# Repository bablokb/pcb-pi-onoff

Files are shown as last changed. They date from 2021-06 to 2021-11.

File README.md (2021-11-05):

pcb-pi-onoff
============

Overview
--------

This project contains the KiCAD-project-files for a small
power-control pHat. A PIC-MCU controls the power for the Pi. On/off is
via a push-button or an IR-remote. Before cutting current, the PIC
sends a shutdown request to the Pi. Once done, the Pi signals
shutdown-complete to the PIC which in turn cuts power.

Status
------

**this is work-in-progress!**

  - production: OK
  - basic firmware: tested
  - basic functional test: open
  - test with RTC: open
  - IR firmware: open
  - IR test: open

PCB
---

The KiCAD-sources for the pHat are in the sub-directory
[pcb-pi-onoff](pcb-pi-onoff), production-files with
gerber-layers, drill-hole files, bom and pick-and-place-file are in
the sub-directory [production](production). Note that the pcb and the
bom/cpl-files are optimzied for JLCPCB. Please check with your
pcb-factory if these files meet their requirements.

Schematic
---------

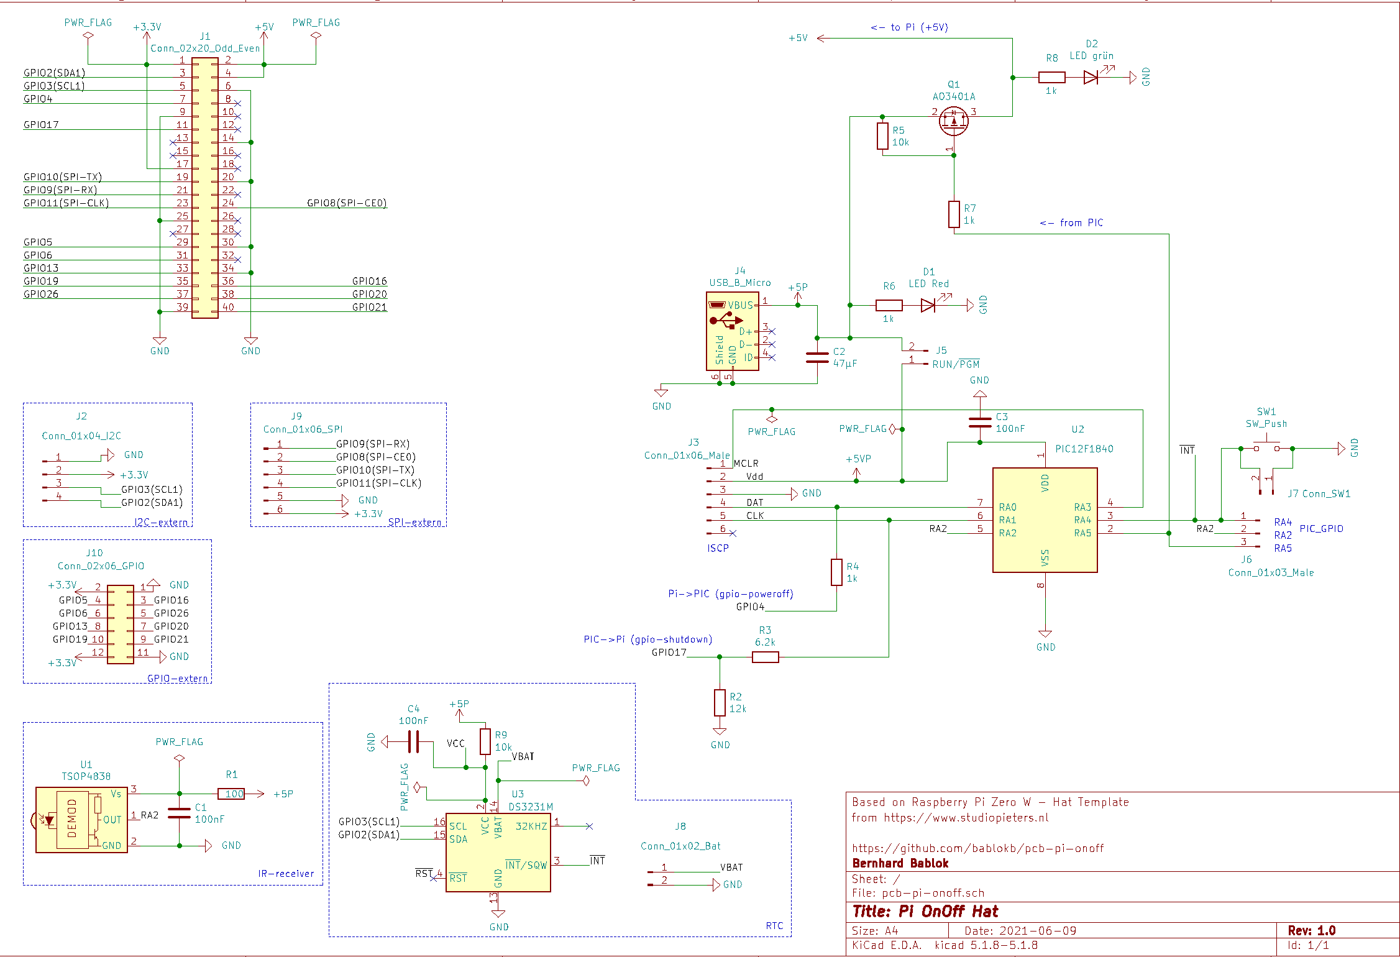
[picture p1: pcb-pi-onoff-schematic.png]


Layout
------

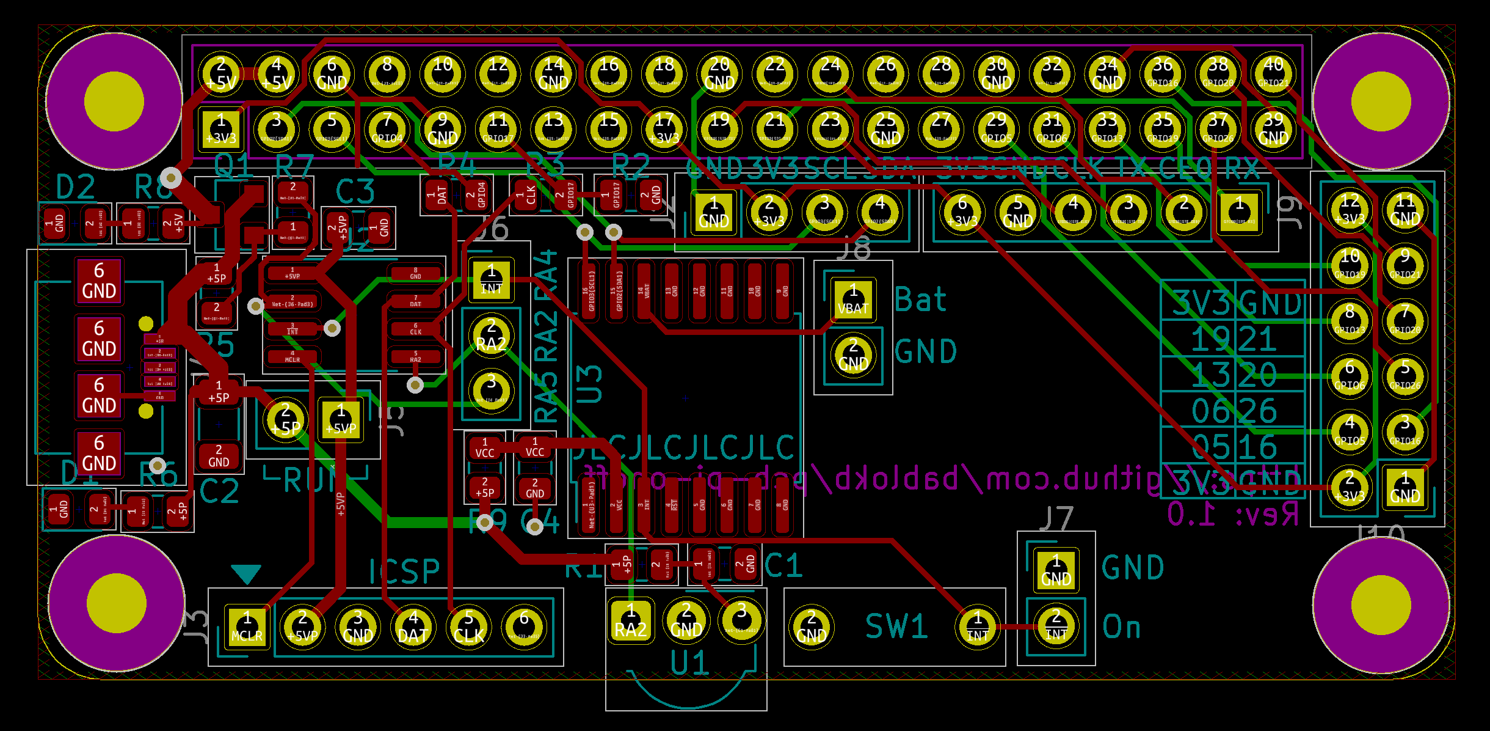
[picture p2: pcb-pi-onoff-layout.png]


3D-View
-------

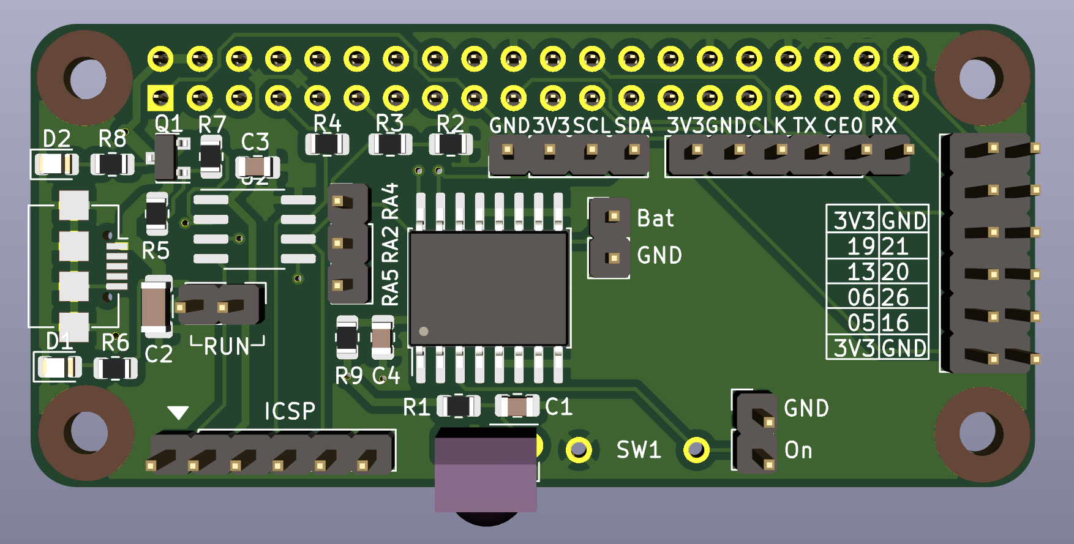
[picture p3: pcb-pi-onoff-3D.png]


Configuration
-------------

Please read the description of the [firmware](pic-firmware/README.md) for
how to configure the Pi and the PIC.

License
-------

[![CC BY-SA 4.0][cc-by-sa-shield]][cc-by-sa]

This work is licensed under a
[Creative Commons Attribution-ShareAlike 4.0 International
License][cc-by-sa].

[][cc-by-sa]

[cc-by-sa]: http://creativecommons.org/licenses/by-sa/4.0/
[cc-by-sa-image]: https://licensebuttons.net/l/by-sa/4.0/88x31.png
[cc-by-sa-shield]:
https://img.shields.io/badge/License-CC%20BY--SA%204.0-lightgrey.svg

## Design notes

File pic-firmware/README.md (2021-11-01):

Firmware
========

About
-----

This is a simple "firmware" for the power-control pHat.

  - The power of the Raspberry Pi is controlled by a PIC using a mosfet.
  - On a signal (high->low), the PIC sets the gate of the mosfet
    to low, thus turning on the Pi. Afterward the PIC waits for
    five seconds. This gives the Pi time to setup it's GPIOs correctly.
  - On an external signal (high->low), the PIC requests the Pi to shutdown by
    setting an output pin to low. This output pin is connected to and
    monitored by the Pi (see below).
  - The Pi now shuts down and at the end sets another pin to high
    This pin in turn is connected to and monitored by the PIC. The PIC
    sets the gate to high thus turning power off.

For the details of the connections, see the
[schematic](../pcb-pi-onoff-schematic.png).

The external signal is connected to a push-button and (optional) to
a RTC.

PIC Configuration
-----------------

  - RA/GP0: PIN_FROM_PI (low->high, connected to GPIO04 on the Pi-side (physical
    pin 7). This is the same pin as in the gpio-poweroff overlay.
  - RA/GP1: PIN_TO_PI (high->low, shutdown-request, monitored by the Pi).
    Connected to GPIO17 on the Pi-side. This is the same pin as in the 
    gpio-shutdown overlay.
  - RA/GP2: PIN_IR (not implemented yet)
  - RA/GP3: only connected to the ICSP-interface
  - RA/GP4: PIN_SIG (high->low, button, RTC)
  - RA/GP5: PIN_POWER (connected to the gate of the mosfet)

In this scenario, the PIC should run at 5V to provide enough voltage to
the gate of the mosfet. So PIN_TO_PI needs a voltage divider when
connected to the Pi (part of the pcb).

Pi Configuration
----------------

On the Pi-side you have to add the following lines in your
/boot/config.xt:

    # initiate shutdown on high->low
    dtoverlay=gpio-shutdown,gpio_pin=17,gpio_pull=off
    # signal shutdown complete on low->high
    dtoverlay=gpio-poweroff,gpiopin=4

Be careful, one overlay needs *gpio_pin*, the other *gpiopin*!

Building
--------

You need sdcc, gpasm and pk2cmd to build and flash the firmware. Please
adapt the paths within the file `rules.inc` to suit your setup.

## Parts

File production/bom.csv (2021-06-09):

Comment | Designator | Footprint | LCSC
47µF | C2 | Capacitor_SMD:C_1206_3216Metric | C96123
100nF | C1,C3,C4 | Capacitor_SMD:C_0805_2012Metric | C24497
LED Red | D1 | LED_SMD:LED_0805_2012Metric | C84256
LED grün | D2 | LED_SMD:LED_0805_2012Metric | C2297
Conn_02x20_Odd_Even | J1 | Connector_PinSocket_2.54mm:PinSocket_2x20_P2.54mm_Vertical
Conn_02x06_GPIO | J10 | Connector_PinHeader_2.54mm:PinHeader_2x06_P2.54mm_Vertical
Conn_01x04_I2C | J2 | Connector_PinHeader_2.54mm:PinHeader_1x04_P2.54mm_Vertical
Conn_01x06_Male | J3 | Connector_PinHeader_2.54mm:PinHeader_1x06_P2.54mm_Vertical
USB_B_Micro | J4 | user:USB_Micro-B_JLCPCB_40942 | C40942
RUN/~PGM~ | J5 | Connector_PinHeader_2.54mm:PinHeader_1x02_P2.54mm_Vertical
Conn_01x03_Male | J6 | Connector_PinHeader_2.54mm:PinHeader_1x03_P2.54mm_Vertical
Conn_SW1 | J7 | Connector_PinHeader_2.54mm:PinHeader_1x02_P2.54mm_Vertical
Conn_01x02_Bat | J8 | Connector_PinHeader_2.54mm:PinHeader_1x02_P2.54mm_Vertical
Conn_01x06_SPI | J9 | Connector_PinHeader_2.54mm:PinHeader_1x06_P2.54mm_Vertical
AO3401A | Q1 | Package_TO_SOT_SMD:SOT-23 | C15127
100 | R1 | Resistor_SMD:R_0805_2012Metric | C17408
12k | R2 | Resistor_SMD:R_0805_2012Metric | C17444
6.2k | R3 | Resistor_SMD:R_0805_2012Metric | C17767
10k | R5,R9 | Resistor_SMD:R_0805_2012Metric | C17414
1k | R4,R6,R7,R8 | Resistor_SMD:R_0805_2012Metric | C17513
SW_Push | SW1 | user:SW_PUSH_SLIM_1x4
TSOP4838 | U1 | OptoDevice:Vishay_MOLD-3Pin
PIC12F1840 | U2 | Package_SO:SO-8_3.9x4.9mm_P1.27mm
DS3231M | U3 | Package_SO:SOIC-16W_7.5x10.3mm_P1.27mm

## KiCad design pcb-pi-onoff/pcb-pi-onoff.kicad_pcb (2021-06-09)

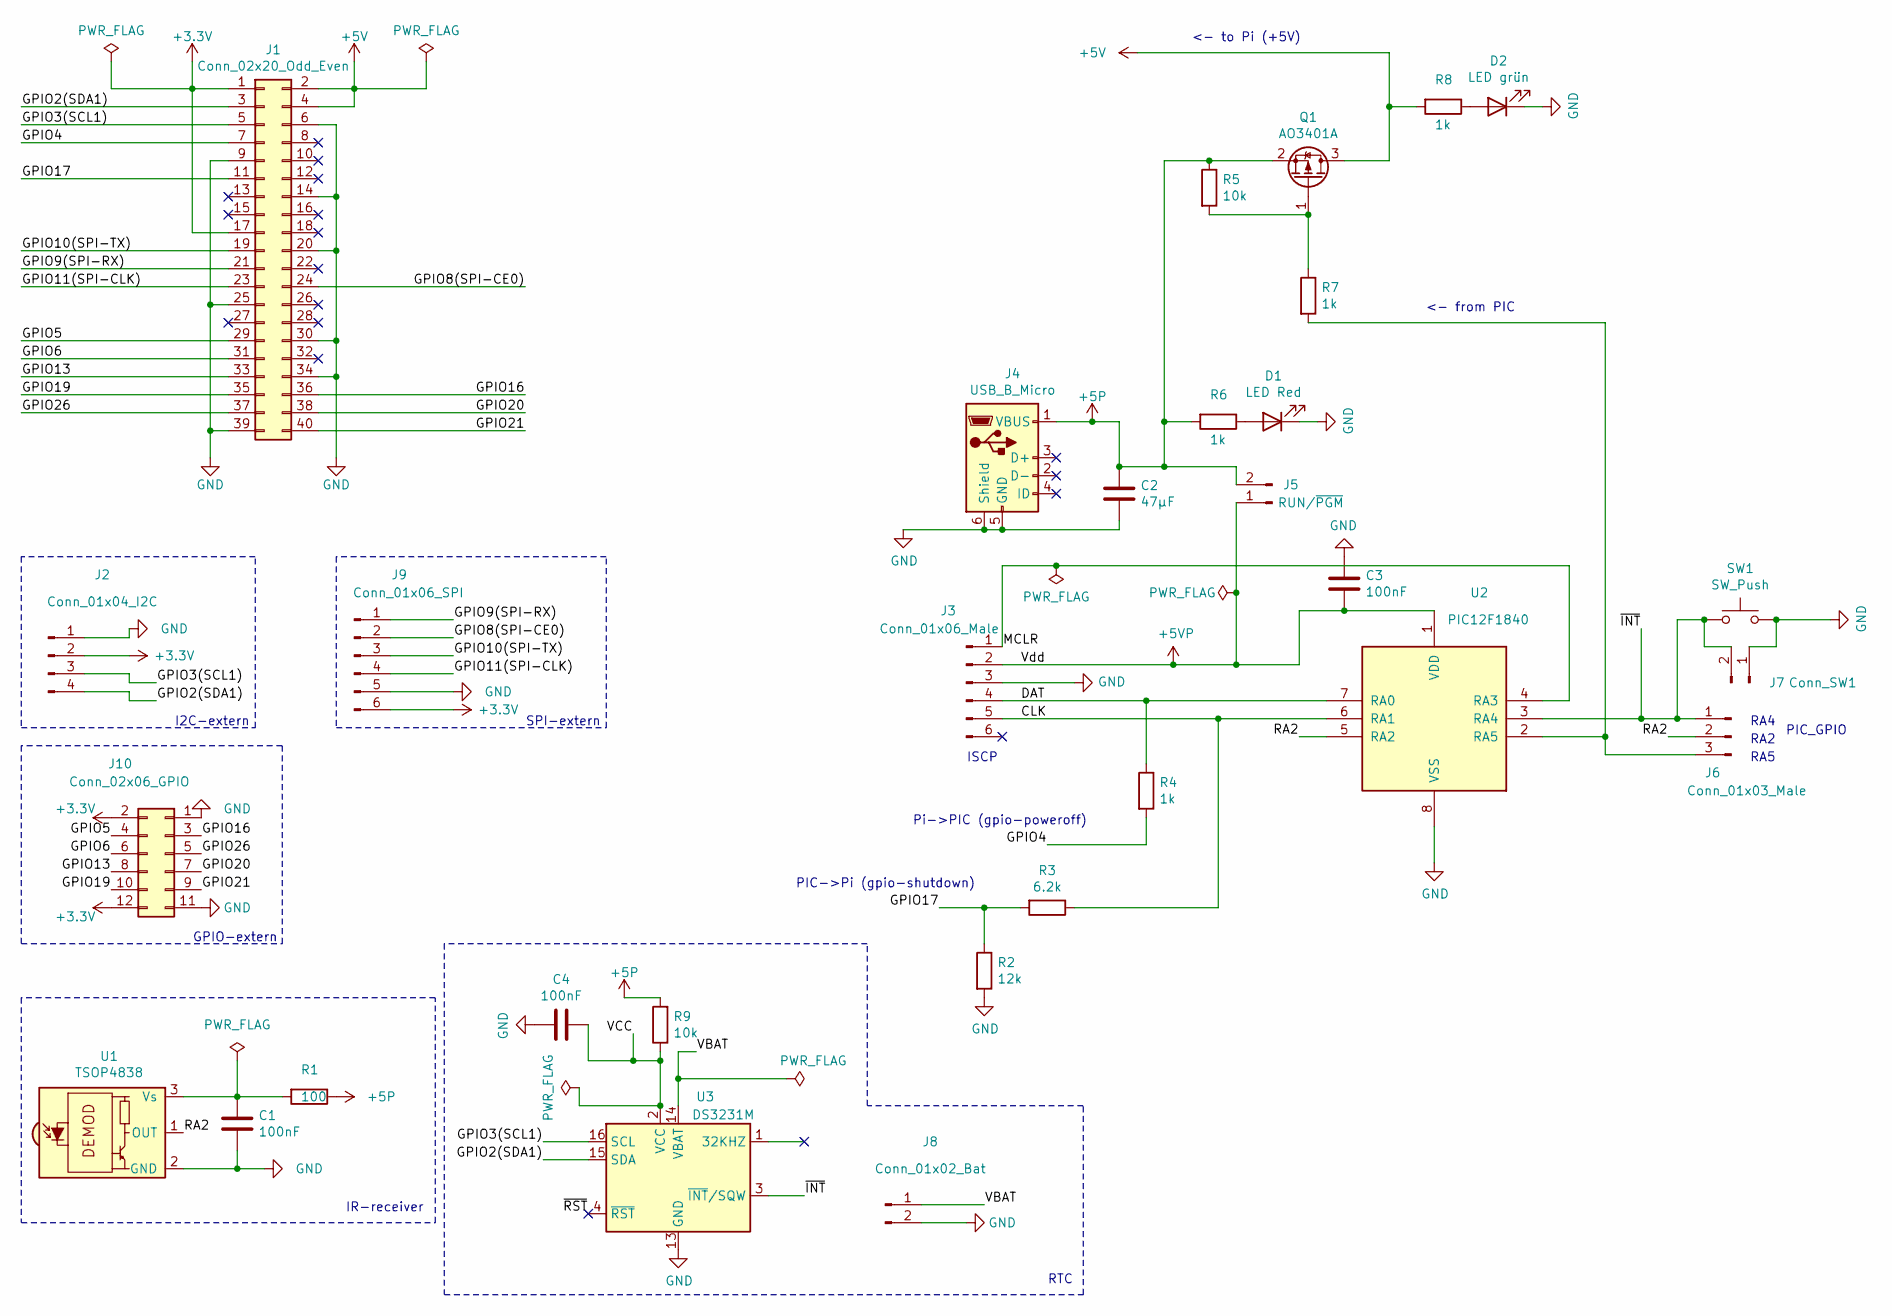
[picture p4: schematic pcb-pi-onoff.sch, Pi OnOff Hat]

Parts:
C1, C3, C4: 100nF; C_0805_2012Metric; LCSC C24497
C2: 47µF; C_1206_3216Metric; LCSC C96123
D1: LED Red; LED_0805_2012Metric; LCSC C84256
D2: LED grün; LED_0805_2012Metric; LCSC C2297
J1: Conn_02x20_Odd_Even; PinSocket_2x20_P2.54mm_Vertical
J2: Conn_01x04_I2C; PinHeader_1x04_P2.54mm_Vertical
J3: Conn_01x06_Male; PinHeader_1x06_P2.54mm_Vertical
J4: USB_B_Micro; USB_Micro-B_JLCPCB_40942; LCSC C40942
J5: RUN/~PGM~; PinHeader_1x02_P2.54mm_Vertical
J6: Conn_01x03_Male; PinHeader_1x03_P2.54mm_Vertical
J7: Conn_SW1; PinHeader_1x02_P2.54mm_Vertical
J8: Conn_01x02_Bat; PinHeader_1x02_P2.54mm_Vertical
J9: Conn_01x06_SPI; PinHeader_1x06_P2.54mm_Vertical
J10: Conn_02x06_GPIO; PinHeader_2x06_P2.54mm_Vertical
Q1: AO3401A; SOT-23; LCSC C15127
R1: 100; R_0805_2012Metric; LCSC C17408
R2: 12k; R_0805_2012Metric; LCSC C17444
R3: 6.2k; R_0805_2012Metric; LCSC C17767
R4, R6, R7, R8: 1k; R_0805_2012Metric; LCSC C17513
R5, R9: 10k; R_0805_2012Metric; LCSC C17414
SW1: SW_Push; SW_PUSH_SLIM_1x4
U1: TSOP4838; Vishay_MOLD-3Pin
U2: PIC12F1840; SO-8_3.9x4.9mm_P1.27mm_HandSolder
U3: DS3231M; SOIC-16W_7.5x10.3mm_P1.27mm_HandSolder

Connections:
+3V3: J1.1, J1.17, J2.2, J9.6, J10.2, J10.12
+5P: C2.1, J4.1 (VBUS), J5.2, Q1.2 (S), R1.1, R5.1, R6.2, R9.2
+5V: J1.2, J1.4, Q1.3 (D), R8.2
+5VP: C3.2, J3.2, J5.1, U2.1 (VDD)
/CLK: J3.5, R3.1, U2.6 (RA1)
/DAT: J3.4, R4.1, U2.7 (RA0)
/GPIO2(SDA1): J1.3, J2.4, U3.15 (SDA)
/GPIO3(SCL1): J1.5, J2.3, U3.16 (SCL)
/GPIO4: J1.7, R4.2
/GPIO5: J1.29, J10.4
/GPIO6: J1.31, J10.6
/GPIO8(SPI-CE0): J1.24, J9.2
/GPIO9(SPI-RX): J1.21, J9.1
/GPIO10(SPI-TX): J1.19, J9.3
/GPIO11(SPI-CLK): J1.23, J9.4
/GPIO13: J1.33, J10.8
/GPIO16: J1.36, J10.3
/GPIO17: J1.11, R2.1, R3.2
/GPIO19: J1.35, J10.10
/GPIO20: J1.38, J10.7
/GPIO21: J1.40, J10.9
/GPIO26: J1.37, J10.5
/MCLR: J3.1, U2.4 (RA3)
/RA2: J6.2, U1.1 (OUT), U2.5 (RA2)
/VBAT: J8.1, U3.14 (VBAT)
/VCC: C4.1, R9.1, U3.2 (VCC)
/~INT: J6.1, J7.2, SW1.1, U2.3 (RA4), U3.3 (~INT~/SQW)
/~RST: U3.4 (~RST)
GND: C1.2, C2.2, C3.1, C4.2, D1.1 (K), D2.1 (K), J1.6, J1.9, J1.14, J1.20, J1.25, J1.30, J1.34, J1.39, J2.1, J3.3, J4.5 (GND), J4.6 (Shield), J7.1, J8.2, J9.5, J10.1, J10.11, R2.2, SW1.2, U1.2 (GND), U2.8 (VSS), U3.5 (GND), U3.6 (GND), U3.7 (GND), U3.8 (GND), U3.9 (GND), U3.10 (GND), U3.11 (GND), U3.12 (GND), U3.13 (GND)
unnamed: C1.1, R1.2, U1.3 (Vs)
unnamed: D1.2 (A), R6.1
unnamed: D2.2 (A), R8.1
unnamed: J6.3, R7.2, U2.2 (RA5)
unnamed: Q1.1 (G), R5.2, R7.1

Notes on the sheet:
PIC_GPIO
ISCP
Pi->PIC (gpio-poweroff)
PIC->Pi (gpio-shutdown)
RA4
RA2
<- from PIC
<- to Pi (+5V)
RA5
I2C-extern
SPI-extern
GPIO-extern
IR-receiver
RTC

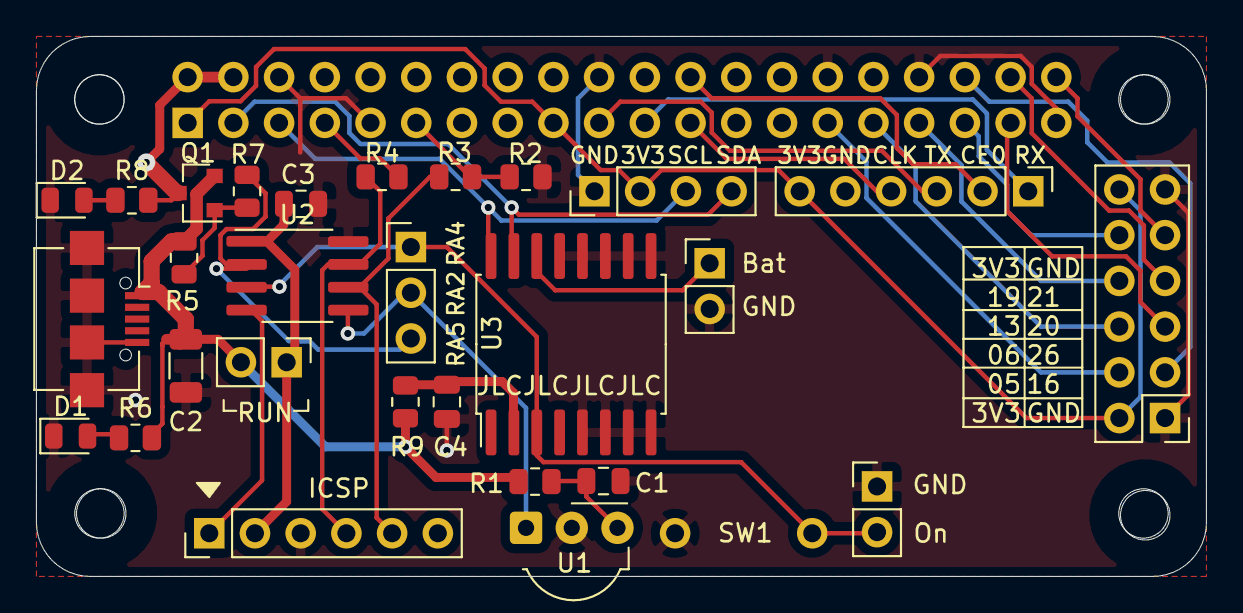
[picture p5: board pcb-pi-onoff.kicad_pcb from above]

Board: 2 copper layers, 65.0 x 30.0 mm, 30 parts (1 on the bottom side), 33 nets.

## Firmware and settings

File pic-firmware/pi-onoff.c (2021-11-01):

// --------------------------------------------------------------------------
// Firmware for power-control pHat
//
// This project uses the following pins:
//  - PIN_FROM_PI (RA0): Pi confirms shutdown (PIC can turn off power)
//  - PIN_TO_PI   (RA1): request shutdown from Pi
//  - PIN_IR      (RA2): infrared signal (not implemented)
//  - PIN_SIG     (RA4): external on/off signal (RTC and button)
//  - PIN_POWER   (RA5): attach to gate of mosfet to turn power on or off
//
// Author: Bernhard Bablok
//
// https://github.com/bablokb/pcb-pi-onoff
// 
// --------------------------------------------------------------------------

#include "picconfig.h"
#include <stdint.h>

#include "delay.h"

#ifndef PIN_FROM_PI
  #define PIN_FROM_PI 0
#endif
#define GP_FROM_PI _CONCAT(RA,PIN_FROM_PI)

#ifndef PIN_TO_PI
  #define PIN_TO_PI 1
#endif
#define GP_TO_PI _CONCAT(RA,PIN_TO_PI)

#ifndef PIN_IR
  #define PIN_IR 2
#endif
#define GP_IR _CONCAT(RA,PIN_IR)

#ifndef PIN_SIG
  #define PIN_SIG 4
#endif
#define GP_SIG _CONCAT(RA,PIN_SIG)

#ifndef PIN_POWER
  #define PIN_POWER 5
#endif
#define GP_POWER _CONCAT(RA,PIN_POWER)

#define BOOT_WAIT   20               // 5s = 20*250ms
#define POWER_ON    0
#define POWER_OFF   1

CONFIG_WORDS;

static uint8_t is_booting = 0;

////////////////////////////////////////////////////////////////////////
// Intialize registers

static void init(void) {
  // configure registers
  __asm__ ("CLRWDT");             // clear WDT even if WDT is disabled
  TRISA     = 0b010101;           // GP4, GP2, GP0 are input
  ANSELA    = 0;                  // no analog input
  CM1CON0   = 0x07;               // disable comparator for GP0-GP2
  WPUA      = 0b010100;           // weak pullups enable on GP2, GP4
  NOT_GPPU  = 0;                  // enable pullups
  IOCAN     = 0b010101;           // IOC for all input pins

  PORTA    = 0;                   // initial value of GPIOs
  GP_POWER = POWER_OFF;           //    except GP_POWER
  GP_TO_PI = 1;                   //    except GP_TO_PI

  INTCON   = 0;                   // clear interrupt flag bits
  IOCIE    = 1;                   // enable IOC
  GIE      = 1;                   // global interrupt enable
}

// --- interrupt service routine   ------------------------------------------

static void isr(void) __interrupt 0 {
  if (IOCIF) {                           // interrupt-on-change
    if (!GP_SIG) {                       // PIN_SIG low
      if (GP_POWER == POWER_OFF) {       // power is off:
        GP_POWER = POWER_ON;             //   turn power on and
        is_booting = 1;                  //   configure wait
      } else {                           // power is on:
        GP_TO_PI = 0;                    //   signal shutdown to Pi
      }
      delay_ms(50);                      // debounce GP_SIG

    } else if (GP_FROM_PI) {             // High: shutdown complete
      GP_POWER = POWER_OFF;              // turn power off
      GP_TO_PI = 1;                      // and restore initial state
      is_booting = 0;                    // (should not be necessary)
    }
    IOCIF = 0;                           // clear IOC interrupt flag
  }
}

// --- main program   -------------------------------------------------------

// - calibrate internal clock
// - initialize registers
// - loop forever (sleep not possible because IOC can't wake device)

void main(void) {
  INIT_SPECIAL;
  init();
  while (1) {
    if (is_booting) {
      GIE = 0;                               // disable interrupts
      for (uint8_t i=0; i<BOOT_WAIT; ++i) {
        delay_ms(250);
      }
      is_booting = 0;
      GIE = 1;                               // global interrupt enable
    }
  }
}

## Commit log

2021-06-08 added url/revision on B.SilkS
    [pcb-pi-onoff.kicad_pcb]
2021-06-08 added I2C-connector
    [pcb-pi-onoff.kicad_pcb, pcb-pi-onoff.sch]
2021-06-08 added SPI-connector
    [pcb-pi-onoff.kicad_pcb, pcb-pi-onoff.sch]
2021-06-08 added GPIO-connector
    [pcb-pi-onoff.kicad_pcb, pcb-pi-onoff.sch]
2021-06-08 replaced footprints for PIC and RTC with handsolder-version
    [pcb-pi-onoff.kicad_pcb, pcb-pi-onoff.sch]
2021-06-09 Rev 1.0: changed 3V3/GND on GPIO-connector
    [bom.csv, pcb-pi-onoff.kicad_pcb, pcb-pi-onoff.sch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]
